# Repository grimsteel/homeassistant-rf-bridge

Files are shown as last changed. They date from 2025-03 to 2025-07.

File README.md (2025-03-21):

# Home Assistant RF + IR Bridge

A wireless module for adding RF and IR capabilities to Home Assistant. Built on an ESP32-S2. Uses the MQTT protocol.

## Firmware

A template ESPHome firmware is included in the `esphome` dir.

## Case

Case coming soon!

## PCB

* Front: includes pin sockets for two CC1101 modules. (allows for RX/TX on multiple freqs if needed)
* Back: space for two 6mm buttons, two IR leds, and one IR receiver.



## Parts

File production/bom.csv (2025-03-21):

Designator | Footprint | Quantity | Value | LCSC Part #
C10, C3, C5, C7 | 0805 | 4 | 10 uF | C15850
C11, C12, C13, C4, C6, C8 | 0603 | 6 | 0.1 uF | C14663
C9 | 0402 | 1 | 1 uF | C52923
D1 | D_SMB | 1 | P6SMB6.8CA/TR13 | C78395
D4 | D_SOD-123 | 1 | 1N5819WS | C8598
D7 | 0603 | 1 | LED | C2286
J1 | USB_C_Receptacle_HCTL_HC-TYPE-C-16P-01A | 1 | USB_C_Receptacle_USB2.0_16P | C19274016
R1 | 0805 | 1 | 47 | C17714
R2 | 0402 | 1 | 220 | C25091
R3 | 0402 | 1 | 330 | C25104
R4, R6 | 0402 | 2 | 10K | C25744
R7, R8 | 0603 | 2 | 5.1K | C23186
SW1, SW2 | SW_Push_1P1T_XKB_TS-1187A | 2 | SW_Push | C318884
U1 | ESP32-S2-MINI-1 | 1 | ESP32-S2-MINI-1 | C3013906
U3 | SOT-223-3_TabPin2 | 1 | AMS1117-3.3 | C6186

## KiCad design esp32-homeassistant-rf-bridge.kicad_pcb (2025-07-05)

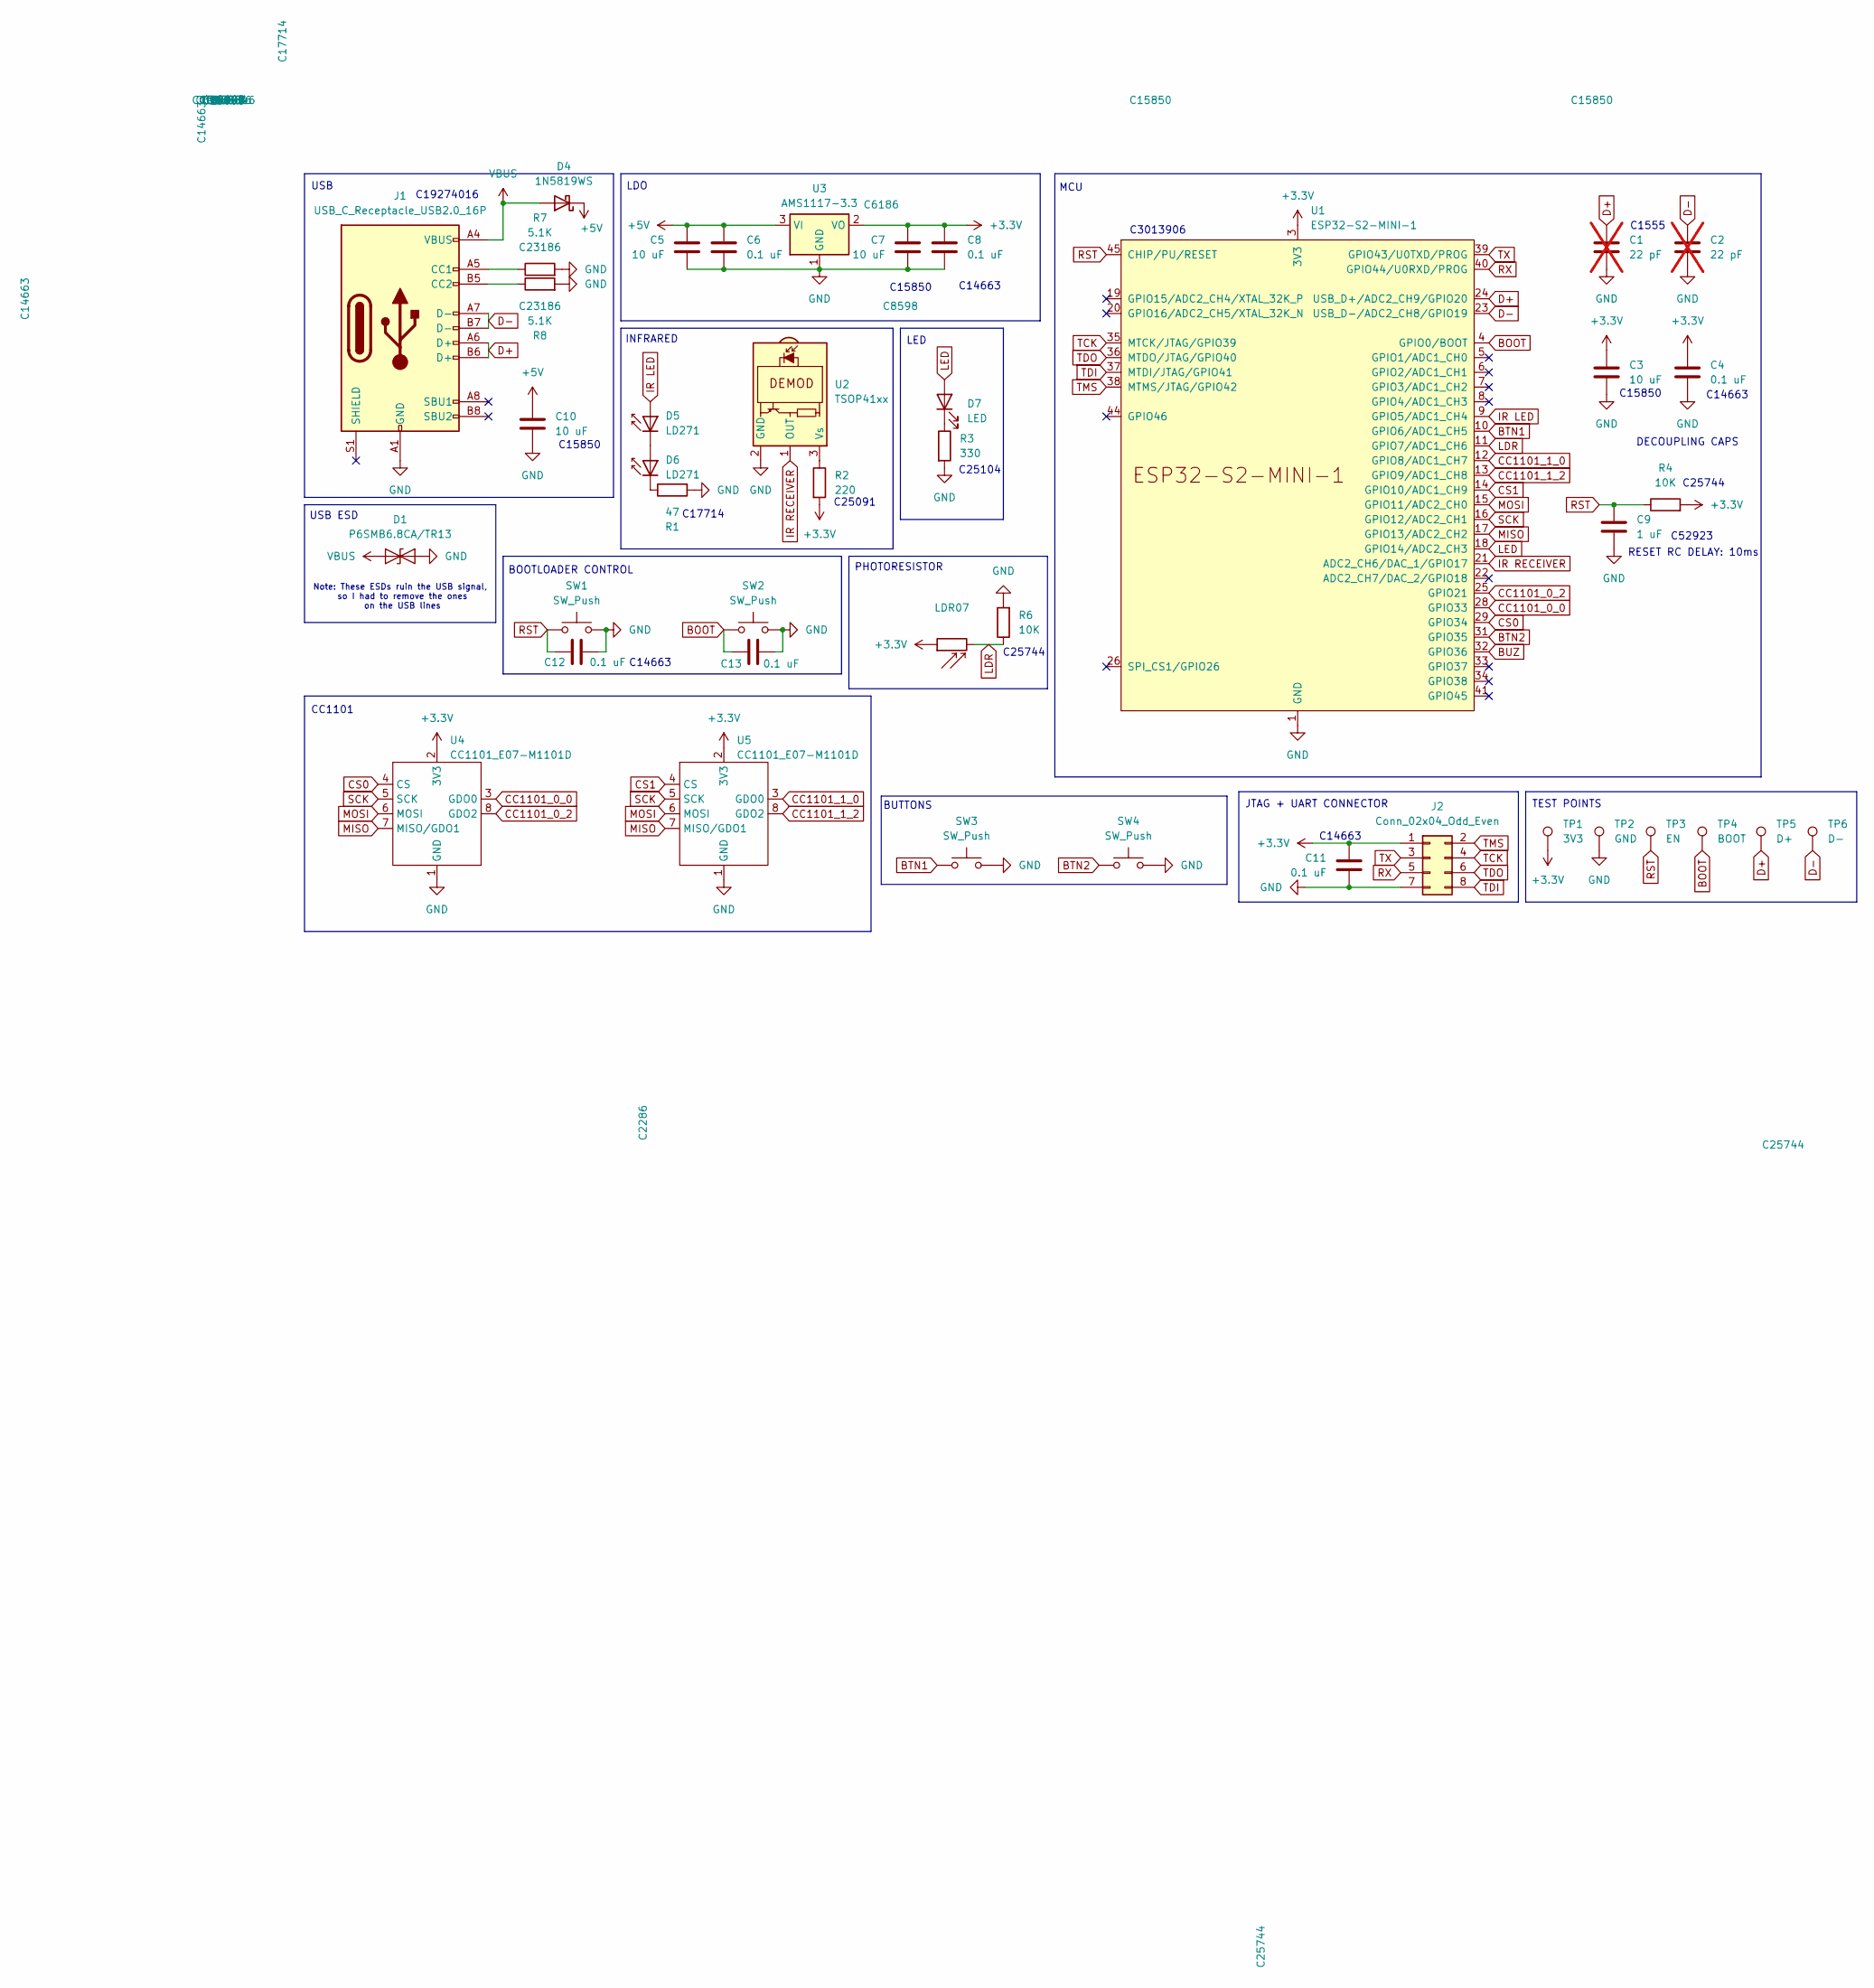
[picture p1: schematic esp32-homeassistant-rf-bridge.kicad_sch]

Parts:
C1, C2: 22 pF; C_0402_1005Metric; LCSC C1555; not fitted
C3, C5, C7, C10: 10 uF; C_0805_2012Metric; LCSC C15850
C4, C6, C8, C11, C12, C13: 0.1 uF; C_0603_1608Metric; LCSC C14663
C9: 1 uF; C_0402_1005Metric; LCSC C52923
D1: P6SMB6.8CA/TR13; D_SMB; LCSC C78395
D4: 1N5819WS; D_SOD-123; LCSC C8598
D5, D6: LD271; LED_D5.0mm_IRGrey
D7: LED; LED_0603_1608Metric; LCSC C2286
J1: USB_C_Receptacle_USB2.0_16P; USB_C_Receptacle_HCTL_HC-TYPE-C-16P-01A; LCSC C19274016
J2: Conn_02x04_Odd_Even; PinHeader_2x04_P2.54mm_Vertical
LDR07: R_LDR_5.0x4.1mm_P3mm_Vertical
R1: 47; R_0805_2012Metric; LCSC C17714
R2: 220; R_0402_1005Metric; LCSC C25091
R3: 330; R_0402_1005Metric; LCSC C25104
R4, R6: 10K; R_0402_1005Metric; LCSC C25744
R7, R8: 5.1K; R_0603_1608Metric; LCSC C23186
SW1, SW2: SW_Push; SW_Push_1P1T_XKB_TS-1187A; LCSC C318884
SW3, SW4: SW_Push; SW_PUSH_6mm
TP1: 3V3; TestPoint_Pad_D3.0mm
TP2: GND; TestPoint_Pad_D3.0mm
TP3: EN; TestPoint_Pad_D3.0mm
TP4: BOOT; TestPoint_Pad_D3.0mm
TP5: D+; TestPoint_Pad_D3.0mm
TP6: D-; TestPoint_Pad_D3.0mm
U1: ESP32-S2-MINI-1; LCSC C3013906
U2: TSOP41xx; Vishay_MOLD-3Pin
U3: AMS1117-3.3; SOT-223-3_TabPin2; LCSC C6186
U4, U5: CC1101_E07-M1101D; CC1101_E07-MM1101D-TH

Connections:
+3.3V: C3.1, C4.1, C7.1, C8.1, C11.1, J2.1, LDR07.1, R2.2, R4.2, TP1.1, U1.3 (3V3), U3.2 (VO), U4.2 (3V3), U5.2 (3V3)
+5V: C5.1, C6.1, C10.1, D4.1 (K), U3.3 (VI)
BOOT: C13.1, SW2.1, TP4.1, U1.4 (GPIO0/BOOT)
BTN1: SW3.1, U1.10 (GPIO6/ADC1_CH5)
BTN2: SW4.1, U1.31 (GPIO35)
BUZ: U1.32 (GPIO36)
CC1101_0_0: U1.28 (GPIO33), U4.3 (GDO0)
CC1101_0_2: U1.25 (GPIO21), U4.8 (GDO2)
CC1101_1_0: U1.12 (GPIO8/ADC1_CH7), U5.3 (GDO0)
CC1101_1_2: U1.13 (GPIO9/ADC1_CH8), U5.8 (GDO2)
CS0: U1.29 (GPIO34), U4.4 (CS)
CS1: U1.14 (GPIO10/ADC1_CH9), U5.4 (CS)
D+: C1.1, J1.A6 (D+), J1.B6 (D+), TP5.1, U1.24 (USB_D+/ADC2_CH9/GPIO20)
D-: C2.1, J1.A7 (D-), J1.B7 (D-), TP6.1, U1.23 (USB_D-/ADC2_CH8/GPIO19)
GND: C1.2, C2.2, C3.2, C4.2, C5.2, C6.2, C7.2, C8.2, C9.2, C10.2, C11.2, C12.2, C13.2, D1.2 (A2), J1.A1 (GND), J1.A12 (GND), J1.B1 (GND), J1.B12 (GND), J2.7, R1.2, R3.2, R6.2, R7.2, R8.2, SW1.2, SW2.2, SW3.2, SW4.2, TP2.1, U1.1 (GND), U1.2 (GND), U1.30 (GND), U1.42 (GND), U1.43 (GND), U1.46 (GND), U1.47 (GND), U1.48 (GND), U1.49 (GND), U1.50 (GND), U1.51 (GND), U1.52 (GND), U1.53 (GND), U1.54 (GND), U1.55 (GND), U1.56 (GND), U1.57 (GND), U1.58 (GND), U1.59 (GND), U1.60 (GND), U1.61 (GND), U1.62 (GND), U1.63 (GND), U1.64 (GND), U1.65 (GND), U2.2 (GND), U3.1 (GND), U4.1 (GND), U5.1 (GND)
IR LED: D5.2 (A), U1.9 (GPIO5/ADC1_CH4)
IR RECEIVER: U1.21 (ADC2_CH6/DAC_1/GPIO17), U2.1 (OUT)
LDR: LDR07.2, R6.1, U1.11 (GPIO7/ADC1_CH6)
LED: D7.2 (A), U1.18 (GPIO14/ADC2_CH3)
MISO: U1.17 (GPIO13/ADC2_CH2), U4.7 (MISO/GDO1), U5.7 (MISO/GDO1)
MOSI: U1.15 (GPIO11/ADC2_CH0), U4.6 (MOSI), U5.6 (MOSI)
unnamed: D5.1 (K), D6.2 (A)
unnamed: D6.1 (K), R1.1
unnamed: D7.1 (K), R3.1
unnamed: J1.A5 (CC1), R7.1
unnamed: J1.B5 (CC2), R8.1
unnamed: R2.1, U2.3 (Vs)
RST: C9.1, C12.1, R4.1, SW1.1, TP3.1, U1.45 (CHIP/PU/RESET)
RX: J2.5, U1.40 (GPIO44/U0RXD/PROG)
SCK: U1.16 (GPIO12/ADC2_CH1), U4.5 (SCK), U5.5 (SCK)
TCK: J2.4, U1.35 (MTCK/JTAG/GPIO39)
TDI: J2.8, U1.37 (MTDI/JTAG/GPIO41)
TDO: J2.6, U1.36 (MTDO/JTAG/GPIO40)
TMS: J2.2, U1.38 (MTMS/JTAG/GPIO42)
TX: J2.3, U1.39 (GPIO43/U0TXD/PROG)
VBUS: D1.1 (A1), D4.2 (A), J1.A4 (VBUS), J1.A9 (VBUS), J1.B4 (VBUS), J1.B9 (VBUS)

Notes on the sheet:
C14663
C25104
LED
LDO
C1555
C52923
BUTTONS
INFRARED
CC1101
MCU
PHOTORESISTOR
TEST POINTS
C17714
JTAG + UART CONNECTOR
C25091
C15850
Note: These ESDs ruin the USB signal, so I had to remove the ones on the USB lines
USB
C25744
DECOUPLING CAPS
RESET RC DELAY: 10ms
C19274016
C3013906
BOOTLOADER CONTROL
USB ESD

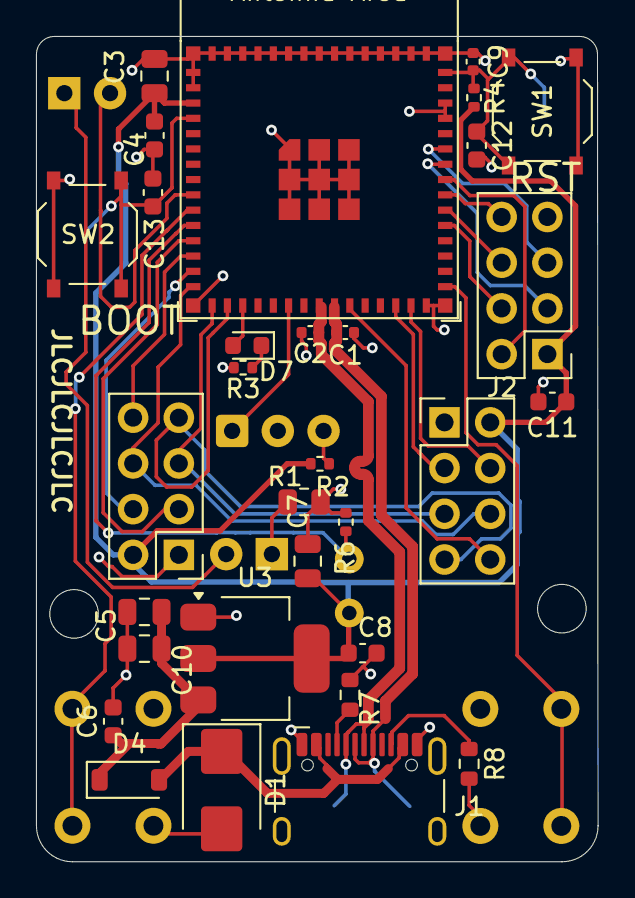
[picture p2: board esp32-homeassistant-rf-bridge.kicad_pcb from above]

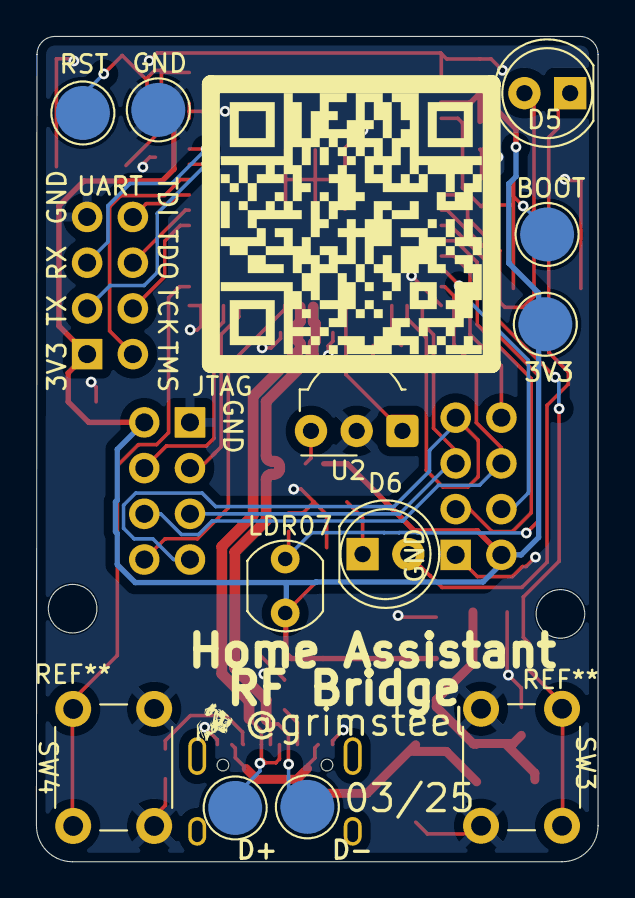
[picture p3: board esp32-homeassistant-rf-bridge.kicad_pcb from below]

Board: 2 copper layers, 31.2 x 45.8 mm, 44 parts (13 on the bottom side), 35 nets.

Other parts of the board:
QR*****: qrcode

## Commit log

2024-12-30 update some silkscreen stuff
    [esp32-homeassistant-rf-bridge.kicad_pcb, esp32-homeassistant-rf-bridge.kicad_sch]
2024-12-30 add more 3d models
    [esp32-homeassistant-rf-bridge.kicad_pcb, esp32-homeassistant-rf-bridge.kicad_sch]
2024-12-30 update production files
    [designators.csv]
2024-12-30 add JLCPCB ID designator
    [esp32-homeassistant-rf-bridge.kicad_pcb]
2024-12-31 silkscreen updates, add LDR and mounting holes
    [esp32-homeassistant-rf-bridge.kicad_pcb, esp32-homeassistant-rf-bridge.kicad_sch]
2025-01-17 make board smaller, remove problematic components
    [bom.csv, designators.csv, esp32-homeassistant-rf-bridge.kicad_pcb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]
2025-03-21 use ams1117
    [bom.csv, designators.csv, esp32-homeassistant-rf-bridge.kicad_pcb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]
2025-07-05 reduce mounting point size
    [esp32-homeassistant-rf-bridge.kicad_pcb]
